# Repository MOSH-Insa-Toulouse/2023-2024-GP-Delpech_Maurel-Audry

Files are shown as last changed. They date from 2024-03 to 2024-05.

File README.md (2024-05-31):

# Projet-MOSH-INSA-Toulouse-2023-2024-Capteur-Graphite
## Implémentation d'un capteur de déformation/jauge de contrainte à base de graphite issu de crayons à papier HB à 2H.
Les jauges de contraintes sont des capteurs résistifs permettant de quantifier la déformation appliquée sur une structure. Ces capteurs sont souvent utilisés dans l'industrie car ils sont peu coûteux et facile à mettre en place. (Pencil Drawn Strain Gauges and Chemiresistors on Paper Cheng-Wei Lin, Zhibo Zhao, Jaemyung Kim & Jiaxing Huang Department of Materials Science and Engineering, Northwestern University 2220 Campus Drive, Evanston, IL, 60208, USA).
La mesure de résistance de ce type de crayon nécessite une amplification nous avons donc créé un Shield Arduino pour le traitement du signal et son affichage.

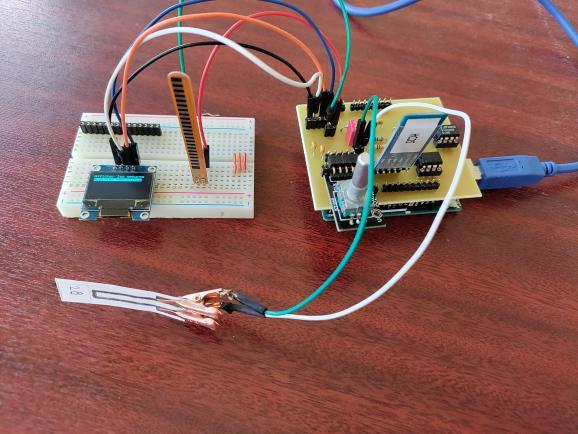
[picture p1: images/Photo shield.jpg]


## Livrables
- Un shield arduino permettant le conditionnement des mesures du capteur graphite, leur traitement et leur affichage.
- Une code arduino permettant le choix du gain de l'amplificateur, la communication en bleutooth via un module HC 05 et l'affichage des mesure sur un écran OLED.
- Une datasheet du capteur de contrainte low-tech

## Hardware utilisé
- 1 carte Arduino Uno
- 1 Module Bluetooth HC-05
- 1 Encodeur rotatoire
- 1 Écran OLED01
- 1 Flex sensor
- 1 Potentiomètre digital MCP-41050
- 1 AOP LTC1050

# Simulation du circuit amplificateur sur LTspice
Un circuit de transimpédance est utilisé pour elever le faible signal du capteur (100nA) à un signal lisible pour le microcontroleur de l'Arduino.

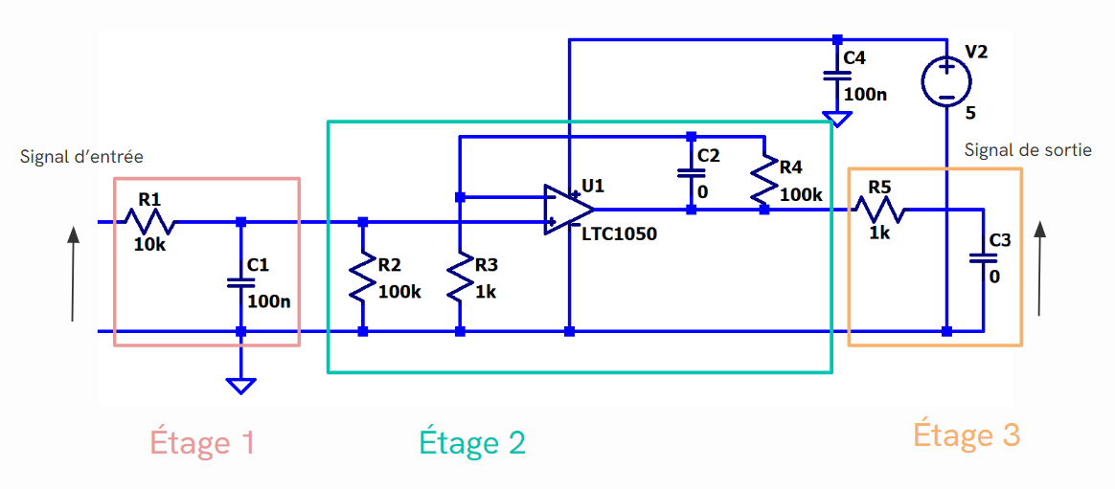
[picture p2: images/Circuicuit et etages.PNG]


Différents étages de filtres passes-bas permettent de couper les hautes fréquences et le 50 Hz et ainsi diminuer le bruit sur la mesure.
  - Fréquence de coupure de l'étage 1 : 16 Hz
  - Fréquence de coupure de l'étage 2 : 1.6 Hz
  - Fréquence de coupure de l'étage 3 : 1.6 kHz

La simulation permet de verifier qu'à 50 Hz le signal est atténué de -40 dB, le bruit du secteur seras alors grandement diminié et ne perturberas pas la mesure. 

# Design du PCB sur KiCAD et fabrication du shield

Le PCB inclu l'amplificateur de transimpédance et différents modules permettant l'affichage ou le traitment des données. En partant d’un template d’une carte Arduino Uno, il a fallu :
  - Reproduire la schématique du circuit transimpédance et créer de nouveaux symboles pour les modules spécifiques à notre projet.
  - Concevoir les empreintes réelles de ces modules en prenant en compte leurs caractéristiques physiques (nombres de pins, distance entre les pins, géométrie des empreintes…)
  - Effectuer le routage du circuit à partir du chevelu
  - Poser le plan de masse pour référencer les pistes au GND

## Schema et empreintes des modules

Module Bluetooth HC 05 : ce module permet la communication des données vers une application androide. L'implemantation d'un échange entre une application et le microcontrolleur permet le stockage de donnée que l'arduino ne permettrais pas. Il permet aussi d'avoir une vue d'ensemble sur les mesures que le petit écran ne permttrais pas.

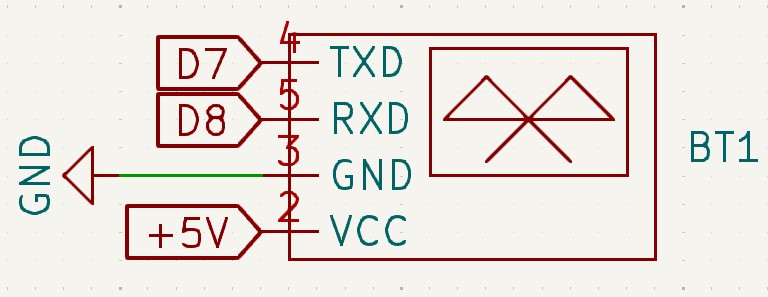
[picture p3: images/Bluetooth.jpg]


L'écran OLED : permet l'affichage des mesures et la selection du gain de l'amplificateur.

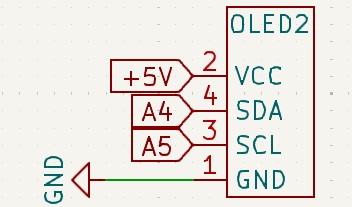
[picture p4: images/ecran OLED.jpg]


L'encodeur rotatoire : permet la navigation dans les menus. Le debouncing de l'encodeur a été réalisé en ajoutant des capacités sur les pins.

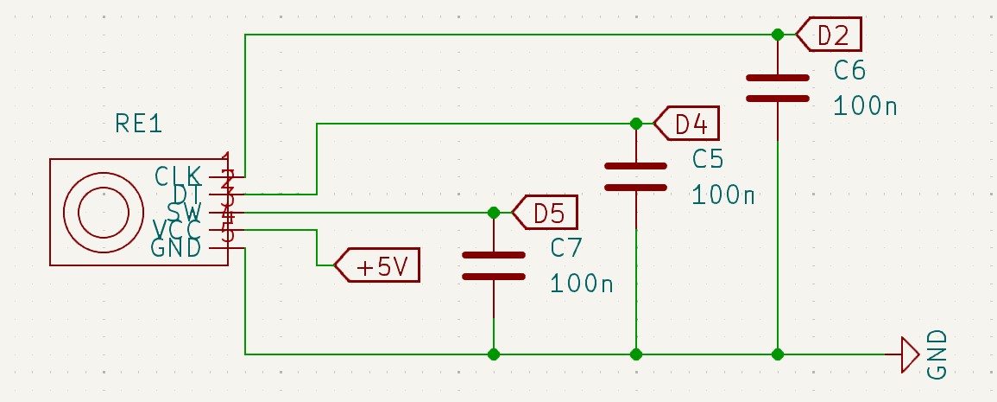
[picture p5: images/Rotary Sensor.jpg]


L'amplificateur de transimpédance avec le capteur graphite.

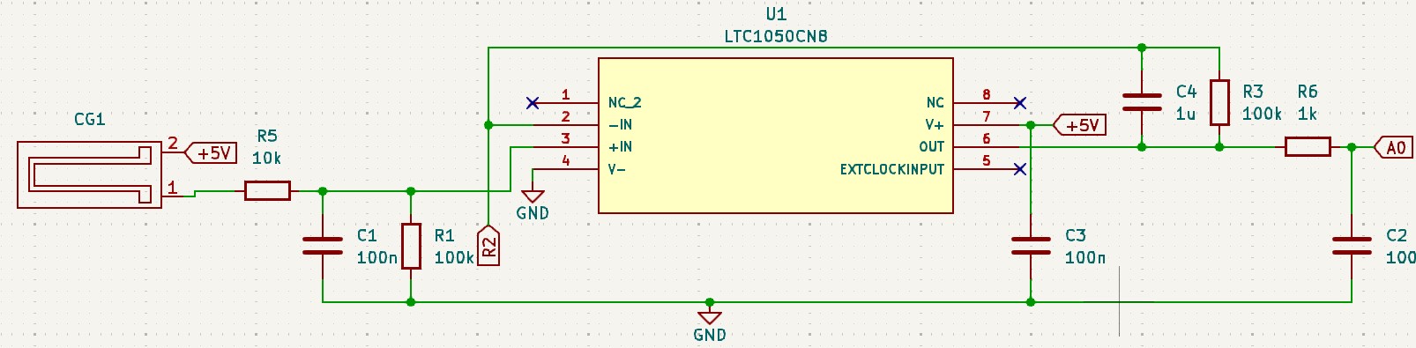
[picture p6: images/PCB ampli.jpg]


La résistance variable digitale MCP41050 : elle permet de changer la résistance R2 de l'amplificateur pour changer le gain.

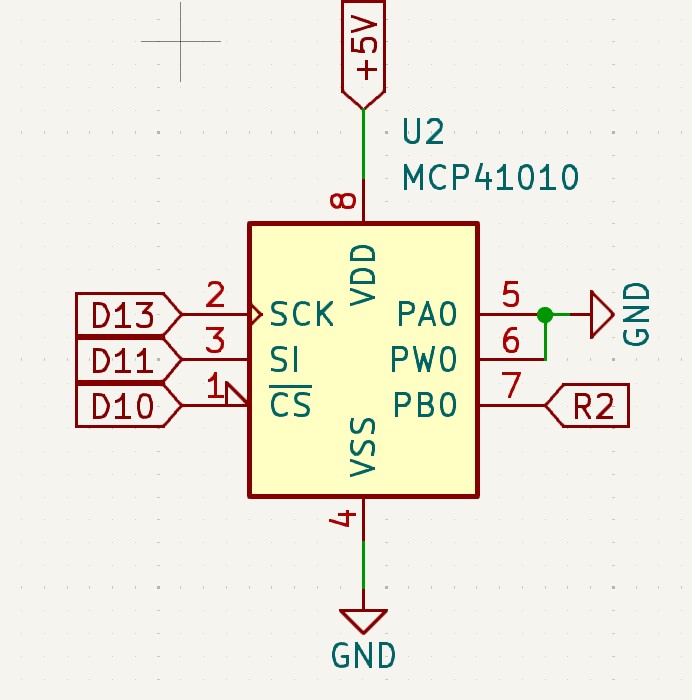
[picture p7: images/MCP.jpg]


## Schema du PCB complet

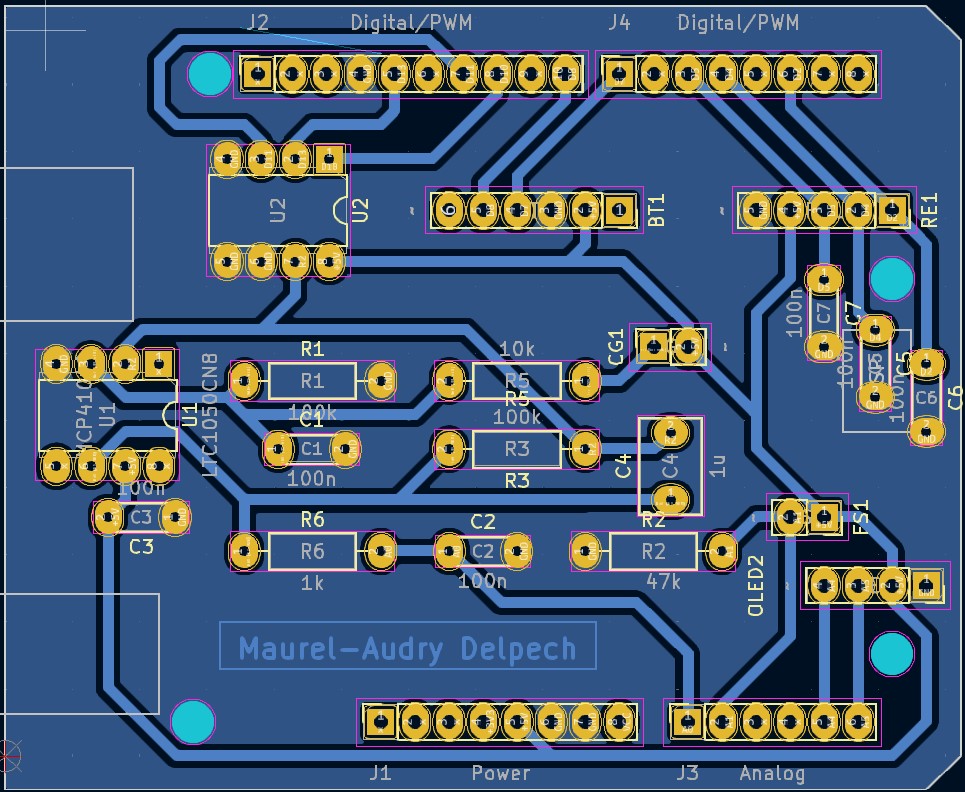
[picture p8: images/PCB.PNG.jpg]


## Fabrication du shield

Le shield est réalisé sur des plaques d'époxy recouvertes d'une couche de cuivre. Une résine photosensible est appliquée sur la plaque avec par dessus, le calque du circuit. Le tout est ensuit placé sous lumière UV pour faire polymeriser la résine au endroits non protégé par le calque. La plque d'époxy est ensuite plongé dans du perchlorure de fer pour retirer la couche de cuivre qui n'est pas protégé par la résine, faisant ainsi apparaître les circuits.

L'étape suivante est de percer les trous pour faire passer les pins de la carte et les composants. Une fois les trous percés, on soude les composants et les headers à la plaque.

# Code Arduino
Le code a été réalisé sous Arduino IDE 2.3.2 et il est consultable 
[ici](https://github.com/MOSH-Insa-Toulouse/2023-2024-GP-Delpech_Maurel-Audry/tree/main/Master_code_projet_capteur).

On utilise la bibliothèque Adafruit_SSD1306 pour gérer l'écran OLED sur lequel on affiche deux sous-menus.
Le premier permet d'afficher la tension après amplification du capteur graphite, la conversion de cette tension en une valeur de résistance et enfin la résistance du capteur de flexion. Le second permet de moduler la résistance du MCP_41050.
Pour naviguer entre les menus et moduler cette résistance, on utilise l'encodeur rotatoire et on clique sur le bouton pour valider ou revenir au menu précédent. 
Les mesures sont ensuite transférées à l'application Android via le module bluetooth. 

# Application android

Le petit écran OLED ne permet pas d'afficher un graph et la petite mémoire de l'arduino ne permet pas de conserver les mesures. Le rôle de l'application android est de pouvoir faciliter l'affichage et le stockage des valeures de déformation.
Pour utiliser l'appliication il faut, dans un premier temps, appairer le telephone au module Bleutooth grâce au menu déroulant de l'app (ne pas oublier d'autoriser l'application à utiliser le bluetooth).
Si le télephone est connecté, l'application recevras les données en continu et les reporteras sur le graphique déroulant. En parrallèle, l'application envoi aussi toutes les mesures sur une page google sheets pour le stockage.

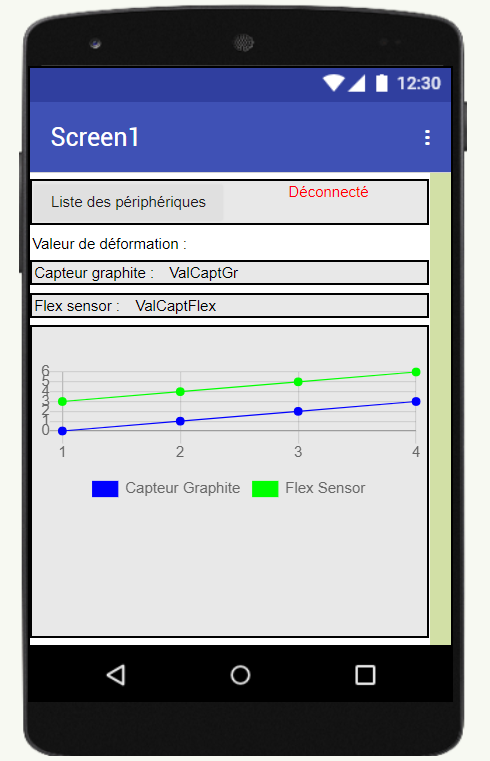
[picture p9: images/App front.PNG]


# Banc de test

Comme banc de test, nous avons utilisé 7 demi cylindres de différents diamètres allant de 2 à 5 cm avec un pas de 0,5 cm. La géométrie des cylindres est connue, il est possbile de remonter à la défromation avec la formule suivante :

$$\epsilon = \frac{e}{2r}$$ 
 
avec e l’épaisseur du capteur et r le rayon de courbure. Les mesures sont réalisées en tension.

2 des différents capteurs utilisés :

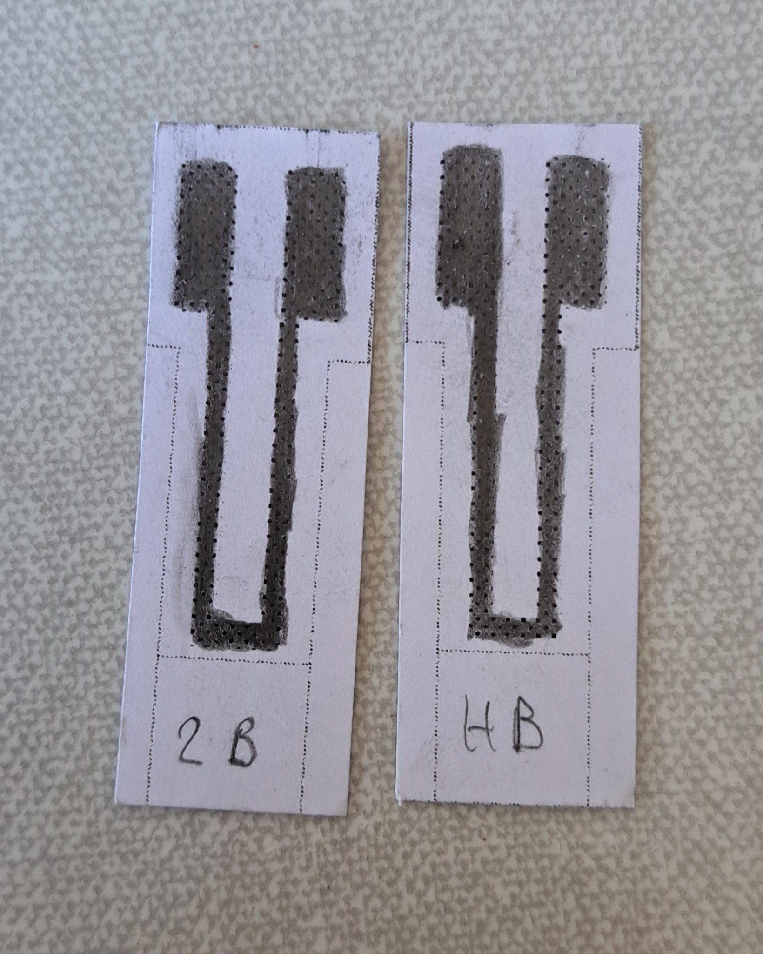
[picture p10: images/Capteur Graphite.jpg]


Suite aux mesures de résistance nous obtenons les courbes suivantes.
Pour l'extension :

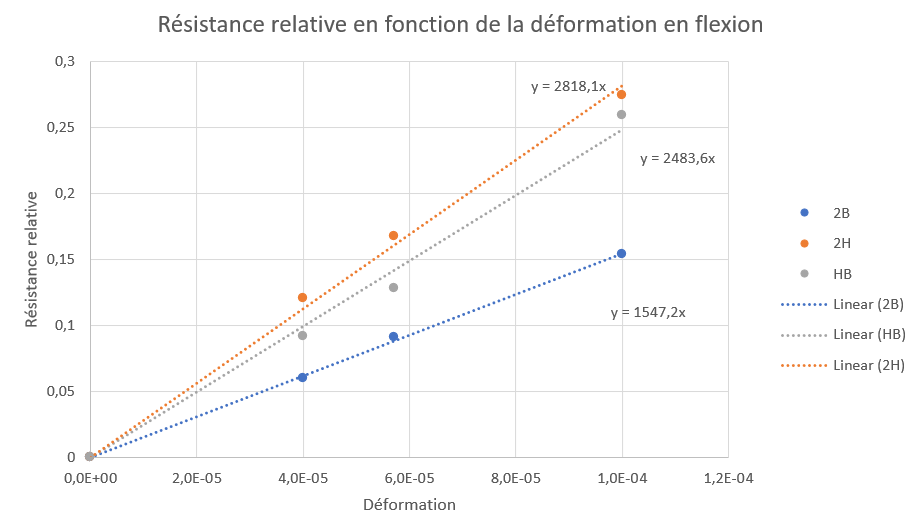
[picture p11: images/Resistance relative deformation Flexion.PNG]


Pour la compression :

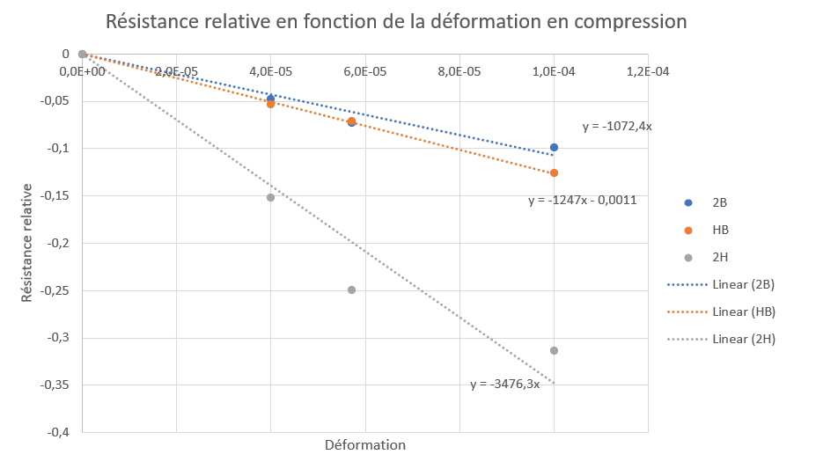
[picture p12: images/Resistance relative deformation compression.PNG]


# Datasheet
La fiche technique est consultable [ici](datasheet.pdf).

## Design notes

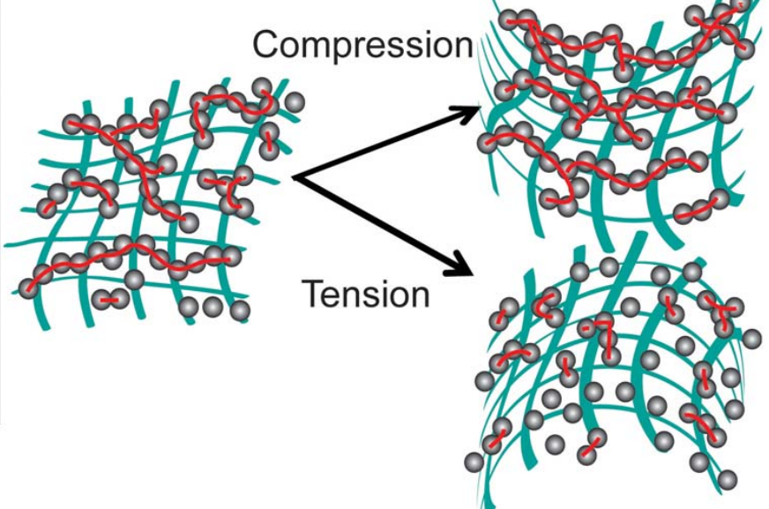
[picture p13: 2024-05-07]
images/Flexion compression.PNG

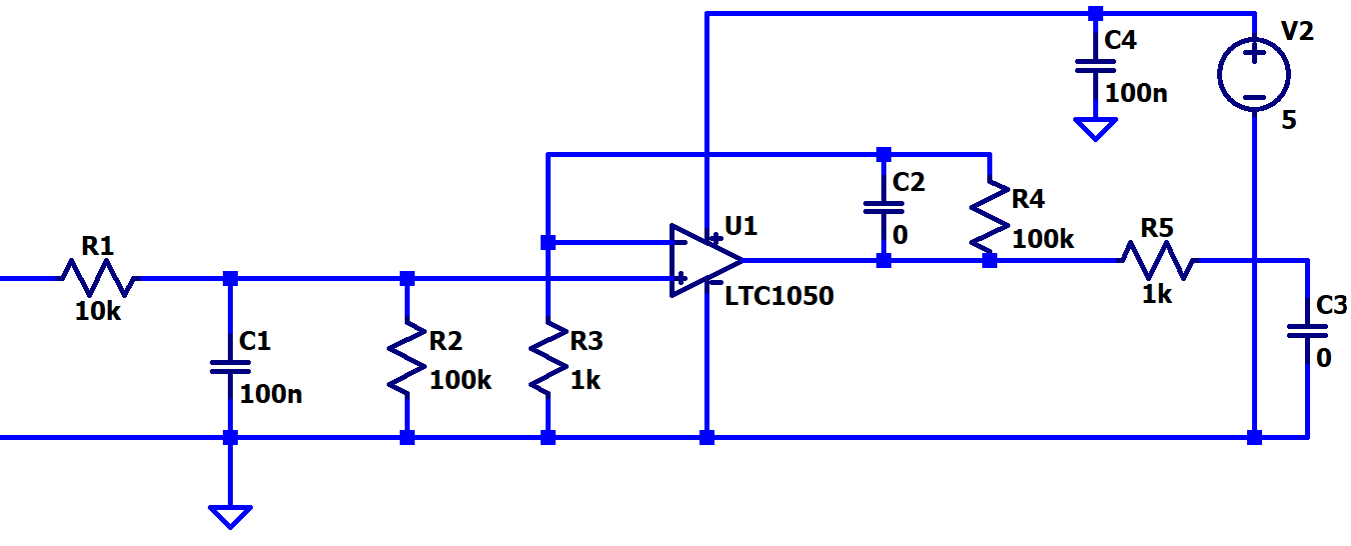
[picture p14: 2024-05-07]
images/circuitcuit.PNG

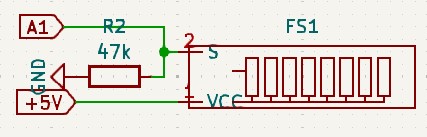
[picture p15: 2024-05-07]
images/Flex sensor.jpg

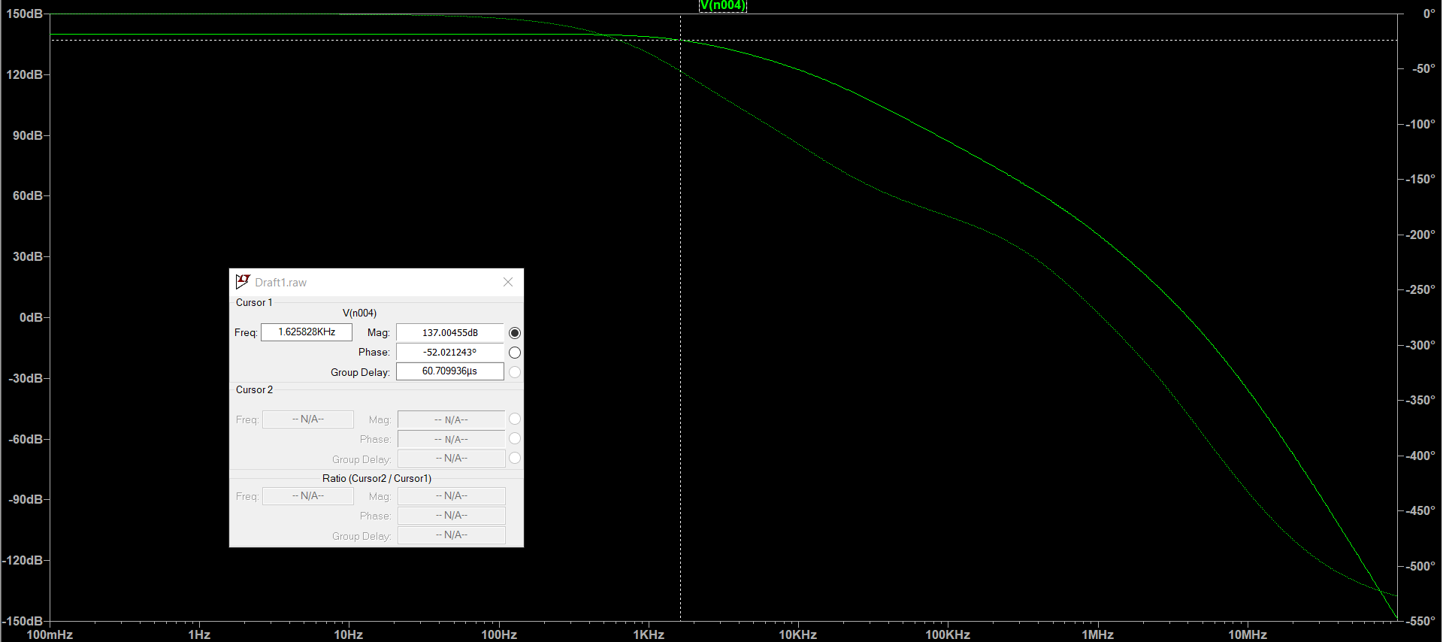
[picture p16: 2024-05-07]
images/Freq coupure 3eme etage.PNG

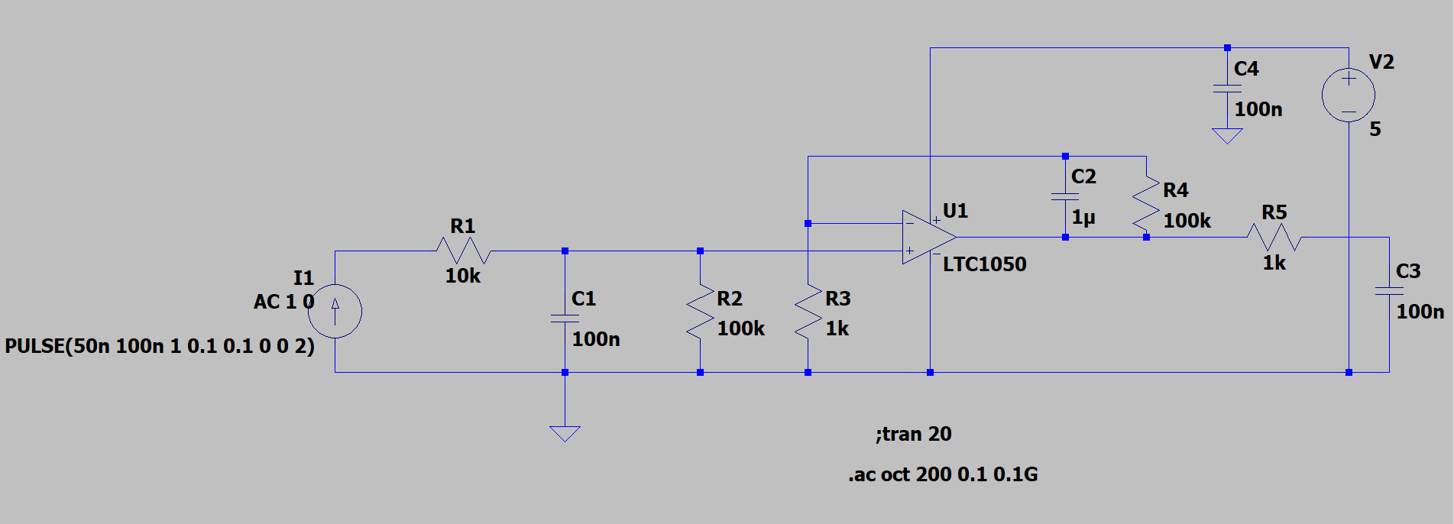
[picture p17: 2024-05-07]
images/Ciruitcuit.PNG

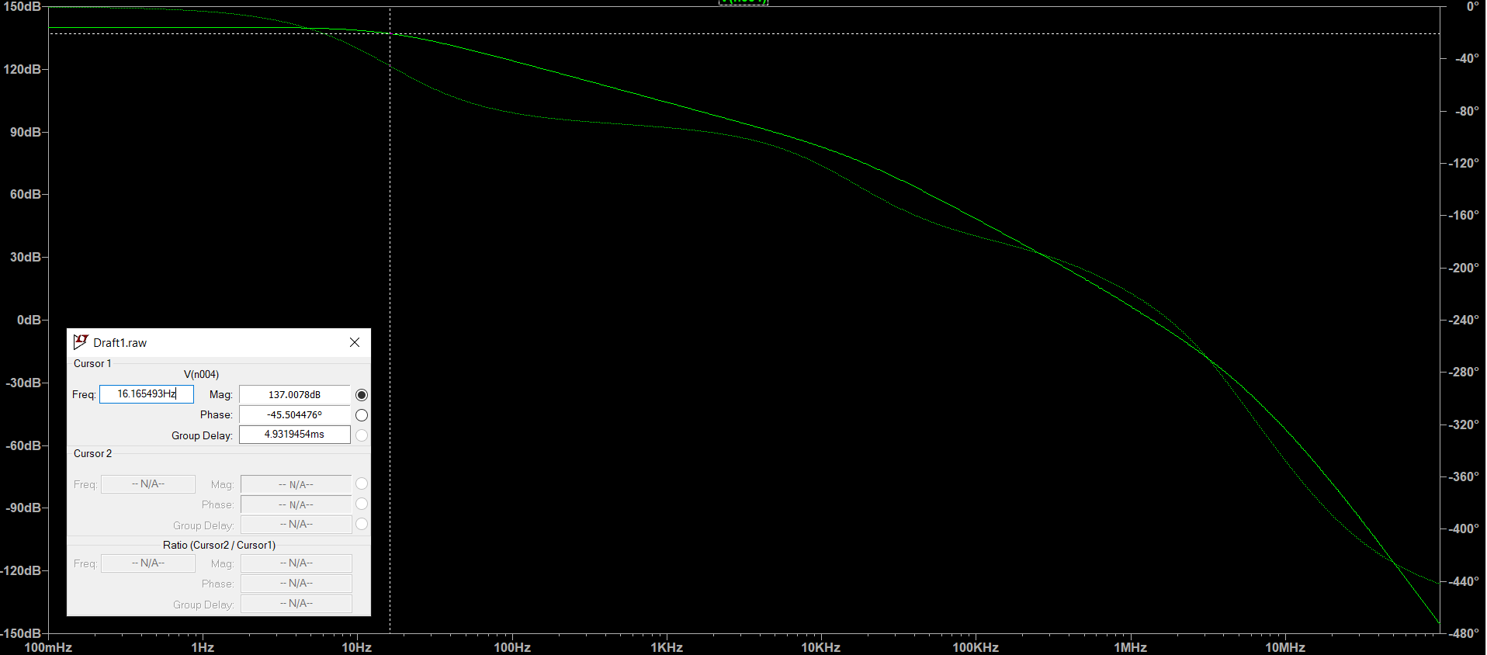
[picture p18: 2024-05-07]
images/freq coupure 1er etage.PNG

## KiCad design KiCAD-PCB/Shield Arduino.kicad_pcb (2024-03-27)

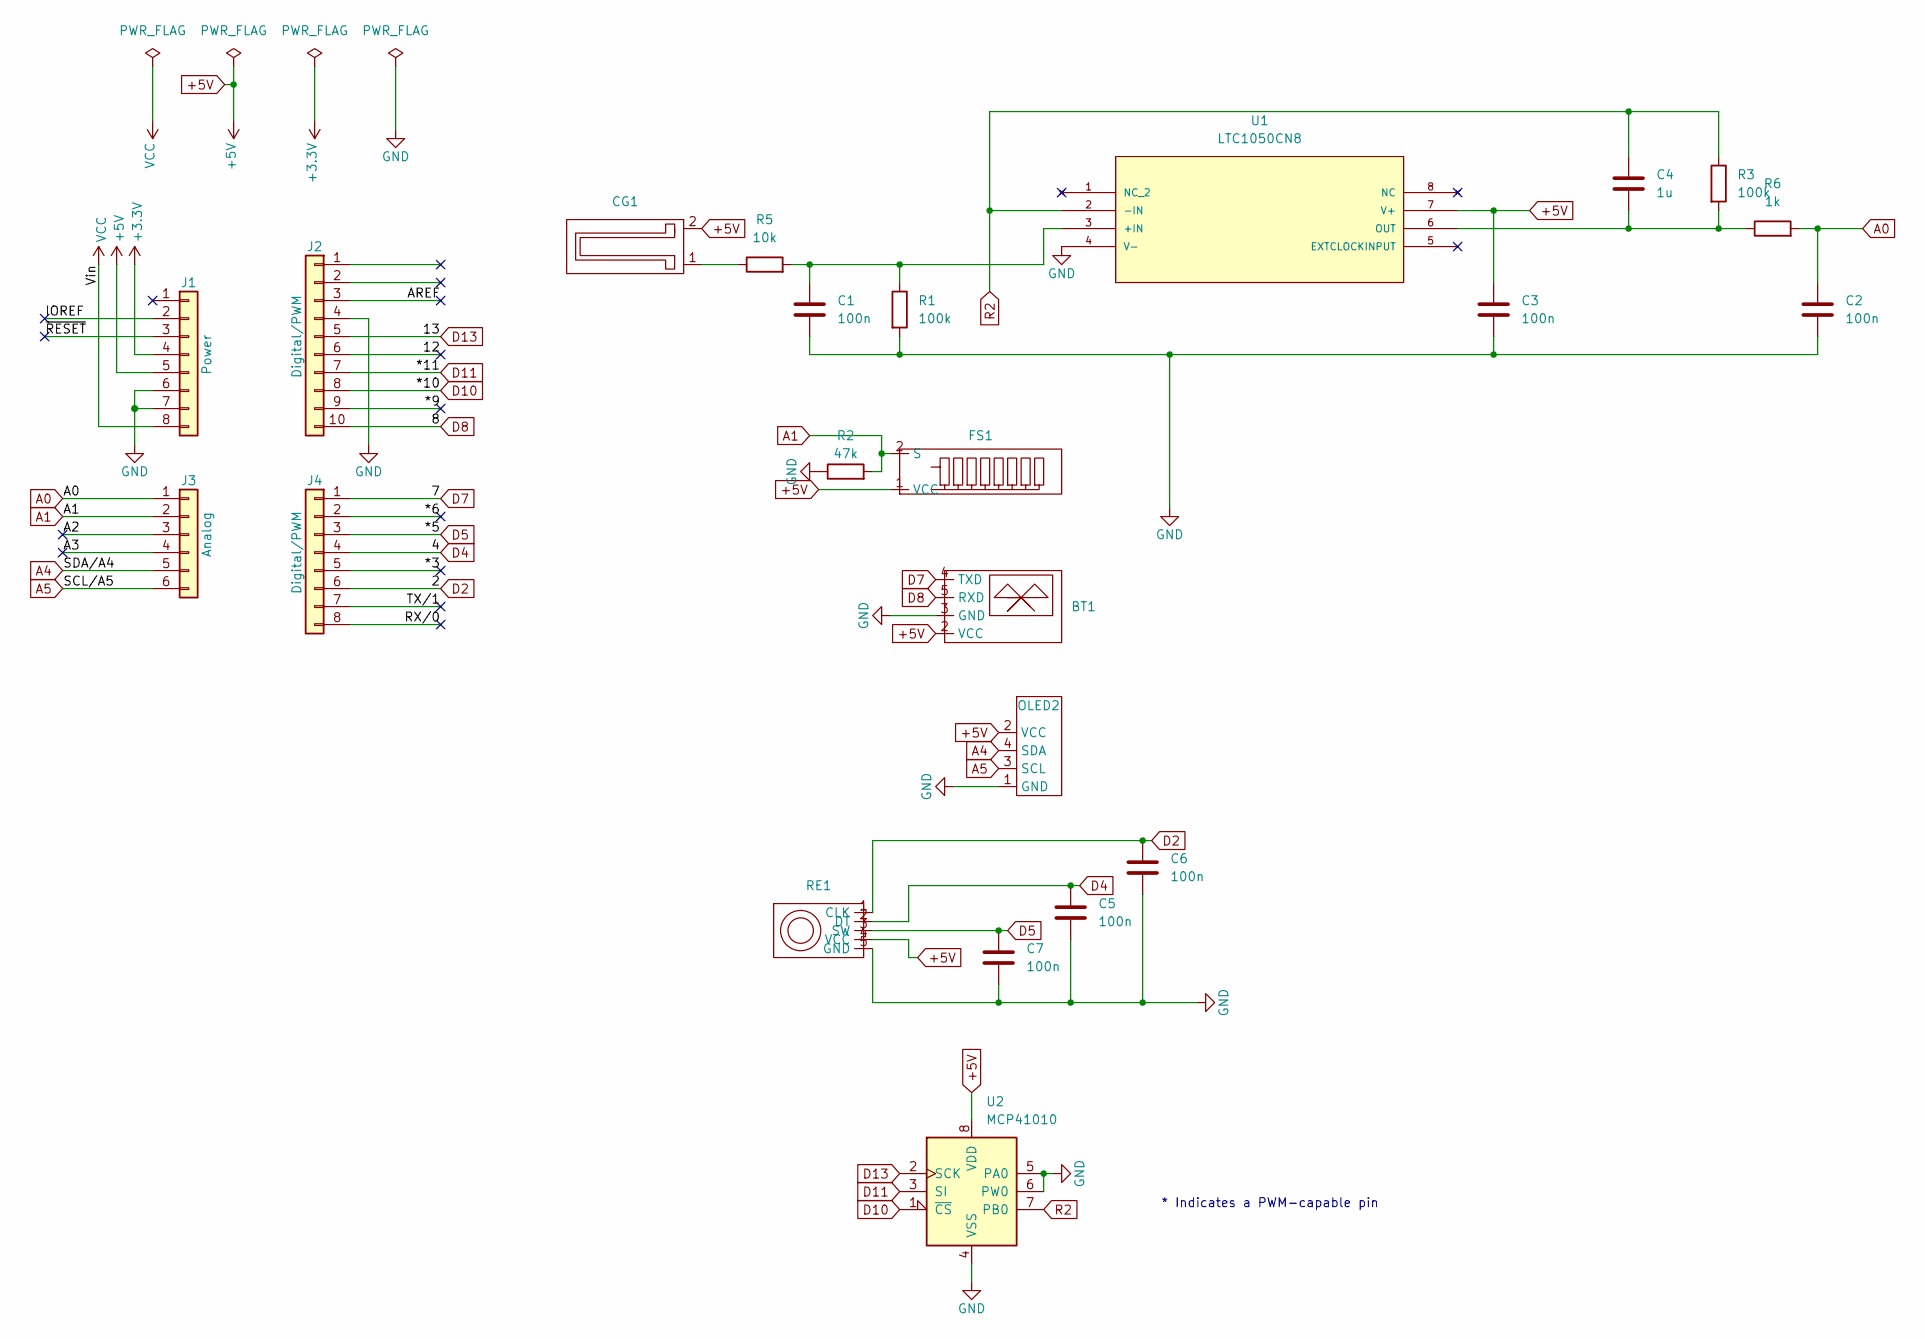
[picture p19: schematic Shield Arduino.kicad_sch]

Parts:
BT1: PinSocket_1x06_P2.54mm_Vertical
C1, C2, C3, C5, C6, C7: 100n; C_Disc_D4.3mm_W1.9mm_P5.00mm
C4: 1u; C_Rect_L7.0mm_W4.5mm_P5.00mm
CG1: PinSocket_1x02_P2.54mm_Vertical
FS1: PinSocket_1x02_P2.54mm_Vertical
J1: Power; PinSocket_1x08_P2.54mm_Vertical
J2: Digital/PWM; PinSocket_1x10_P2.54mm_Vertical
J3: Analog; PinSocket_1x06_P2.54mm_Vertical
J4: Digital/PWM; PinSocket_1x08_P2.54mm_Vertical
OLED2: PinSocket_1x04_P2.54mm_Vertical
R1, R3: 100k; R_Axial_DIN0207_L6.3mm_D2.5mm_P10.16mm_Horizontal
R2: 47k; R_Axial_DIN0207_L6.3mm_D2.5mm_P10.16mm_Horizontal
R5: 10k; R_Axial_DIN0207_L6.3mm_D2.5mm_P10.16mm_Horizontal
R6: 1k; R_Axial_DIN0207_L6.3mm_D2.5mm_P10.16mm_Horizontal
RE1: PinSocket_1x05_P2.54mm_Vertical
U1: LTC1050CN8; DIP-8_W7.62mm
U2: MCP41010; DIP-8_W7.62mm

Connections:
+3V3: J1.4
+5V: BT1.2 (VCC), C3.2, CG1.2, FS1.1 (VCC), J1.5, OLED2.2 (VCC), RE1.4 (VCC), U1.7 (V+), U2.8 (VDD)
/12: J2.6
/*3: J4.5
/*6: J4.2
/*9: J2.9
/A2: J3.3
/A3: J3.4
/AREF: J2.3
/IOREF: J1.2
/RX/0: J4.8
/TX/1: J4.7
/~RESET: J1.3
A0: C2.1, J3.1, R6.2
A1: FS1.2 (S), J3.2, R2.2
A4: J3.5, OLED2.4 (SDA)
A5: J3.6, OLED2.3 (SCL)
D2: C6.1, J4.6, RE1.1 (CLK)
D4: C5.1, J4.4, RE1.2 (DT)
D5: C7.1, J4.3, RE1.3 (SW)
D7: BT1.4 (TXD), J4.1
D8: BT1.5 (RXD), J2.10
D10: J2.8, U2.1 (~CS)
D11: J2.7, U2.3 (SI)
D13: J2.5, U2.2 (SCK)
GND: BT1.3 (GND), C1.2, C2.2, C3.1, C5.2, C6.2, C7.2, J1.6, J1.7, J2.4, OLED2.1 (GND), R1.2, R2.1, RE1.5 (GND), U1.4 (V-), U2.4 (VSS), U2.5 (PA0), U2.6 (PW0)
unnamed: CG1.1, R5.1
unnamed: C1.1, R1.1, R5.2, U1.3 (+IN)
unnamed: C4.1, R3.2, R6.1, U1.6 (OUT)
R2: C4.2, R3.1, U1.2 (-IN), U2.7 (PB0)
VCC: J1.8

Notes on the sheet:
* Indicates a PWM-capable pin

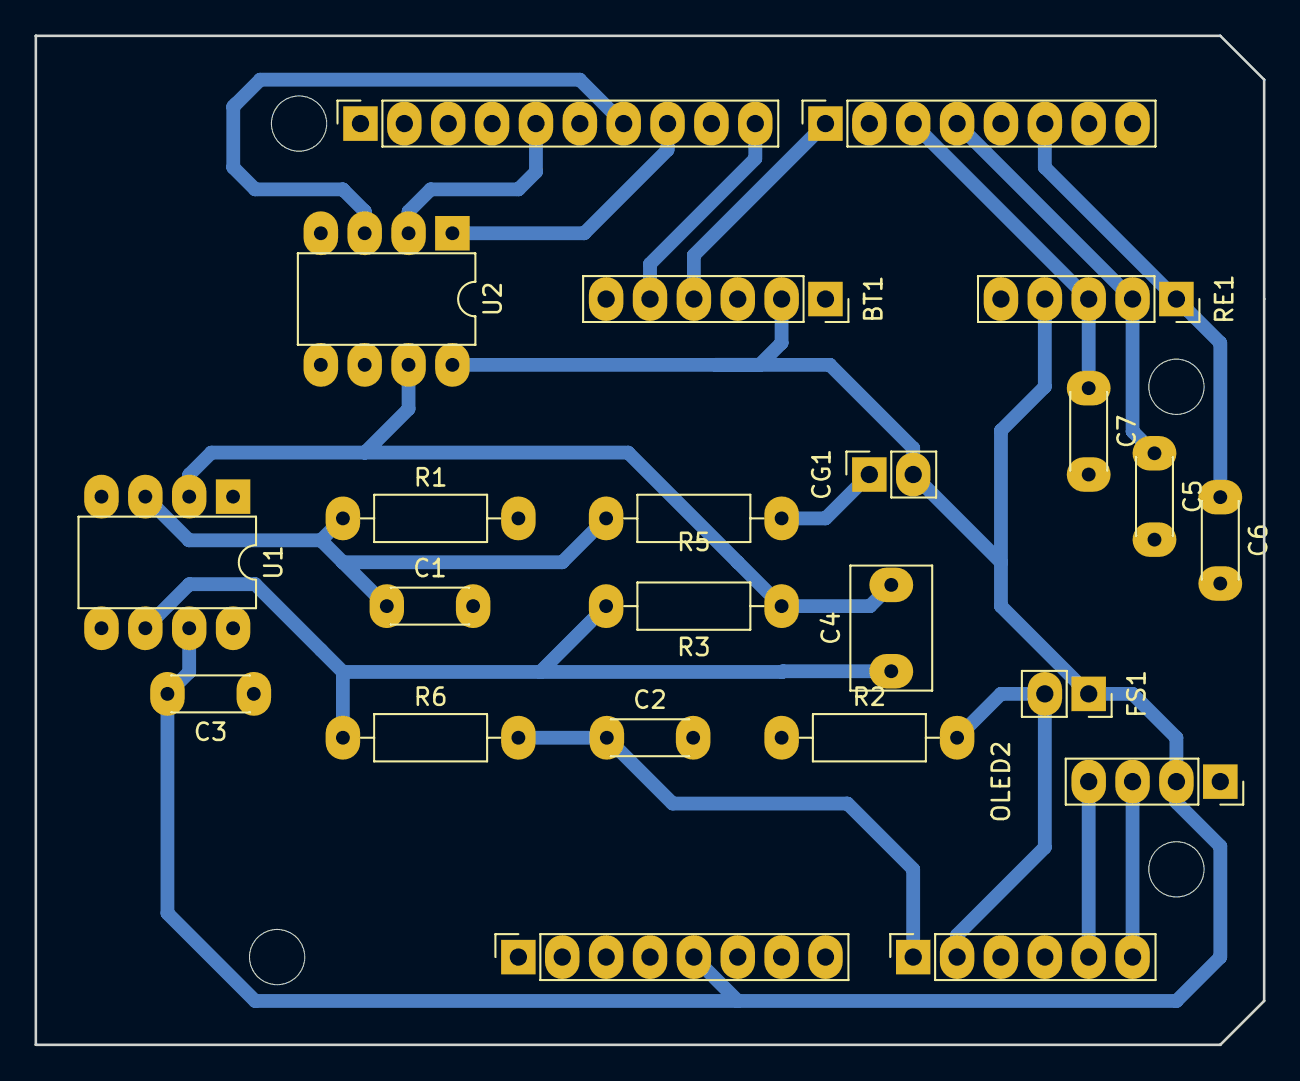
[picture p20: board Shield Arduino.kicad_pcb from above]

Board: 2 copper layers, 71.1 x 58.4 mm, 27 parts (0 on the bottom side), 18 nets.

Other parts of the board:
MH1, MH2, MH3, MH4: MountingHole_3.2mm

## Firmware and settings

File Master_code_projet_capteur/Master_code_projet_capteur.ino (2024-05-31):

#include <Wire.h>
#include <Adafruit_GFX.h>
#include <Adafruit_SSD1306.h>
#include <SPI.h>
#include <SoftwareSerial.h>


//Définition des pins analogiques pour les capteurs

#define PIN_GRAPH_SENSOR A0 // Capteur graphite sur l'entrée analogique A0
#define PIN_FLEX_SENSOR A1 // Capteur de flexion sur l'entrée A1

// Définition des pins numériques pour l'encodeur rotatoire
#define CLK  2  
#define DT  4  
#define Switch 5 

//Définition des broches RXD et TXD du module Bluetooth HC-05
#define bluetoothTx 7 // Broche TXD du module Bluetooth connectée à la broche 7 d'Arduino
#define bluetoothRx 8 // Broche RXD du module Bluetooth connectée à la broche 8 d'Arduino

// Déclaration d'un objet de type SoftwareSerial pour la communication avec le module Bluetooth
SoftwareSerial bluetooth(bluetoothTx, bluetoothRx);

// Déclaration de l'écran OLED avec la bibliothèque AdaFruit

#define SCREEN_WIDTH 128    // Taille horizontale de l'écran OLED  
#define SCREEN_HEIGHT 64    // Taille verticale 
#define OLED_RESET    -1    // Reset de l'écran est le même que celui de l'Arduino Uno
#define SCREEN_ADDRESS 0x3C // Adresse I2C de l'écran

Adafruit_SSD1306 oled(SCREEN_WIDTH, SCREEN_HEIGHT, &Wire, OLED_RESET);

// Déclaration pour les menus de l'écran
int selectedItem = 0;
bool inSubMenu = false;
const int numItems = 2;
const char *menuItems[] = {"Afficher les mesures", "Modifier resistance"};

// Déclaration pour le potentiomètre digital
const byte csPin           = 10;      
const int  maxPositions    = 256;     
const long rAB             = 50000.0;    
const byte rWiper          = 125;     
const byte pot0            = 0x11;    // pot0 addr // B 0001 0001
const byte pot0Shutdown    = 0x21;    // pot0 shutdown // B 0010 0001
int pos_res_variable = 5; // Fixe la résistance initiale du potentiomètre digital

// Déclaration pour le capteur de flexion et le capteur graphite
const float VCC = 5;
const float flexR_DIV = 39000.0;
const float flexflatResistance = 25000.0;
const float flexbendResistance = 100000.0;
float tension_graphite = 0;
float tension_flex = 0;
long resistance_variable = 0;
float resistance_graphite = 0;
long resistance_flex = 0;
char resultGraphite[15];
char buffer[15];
char resultFlex[15];
char buffer_flex[15];

// Déclaration pour l'encodeur rotatoire
volatile unsigned int lastStateSW; // variable qui enregistre l'état du bouton à la boucle précédente

/* ~~~~ Initialisation du programme ~~~~~ */

void setup() {
  Serial.begin(9600);
  bluetooth.begin(9600);
  
 // Initialisation des pins 
  pinMode(CLK, INPUT_PULLUP);
  pinMode(DT, INPUT_PULLUP);
  pinMode(Switch, INPUT_PULLUP);
  pinMode(PIN_GRAPH_SENSOR, INPUT);
  pinMode(PIN_FLEX_SENSOR, INPUT);
    
  lastStateSW = digitalRead(Switch); // Vérifie l'état du bouton au lancement du programme

  attachInterrupt(0, doEncoder, RISING); //Définit l'interruption lorsque l'encodeur rotatoire tourne
 
 // Initialisation de l'écran
 if(!oled.begin(SSD1306_SWITCHCAPVCC, SCREEN_ADDRESS)) {
    Serial.println(F("SSD1306 allocation failed"));
    for(;;);
  }
  oled.setTextSize(1);
  oled.display();
  delay(2000);
  oled.clearDisplay();

 // Initialisation de la communication avec le potentiomètre digital
  digitalWrite(csPin, HIGH);        
  pinMode(csPin, OUTPUT);           
  SPI.begin();

}

/* ~~~~ Programme principal ~~~~~ */

void loop() {

  // Lecture de l'état du bouton pour passer du menu et aux sous-menus
  int stateSW = digitalRead(Switch);
  if (stateSW != lastStateSW && stateSW == LOW) {
    Serial.println(F("Clic!"));
    inSubMenu = !inSubMenu;
  }
  lastStateSW = stateSW;

  setPotWiper(pot0,pos_res_variable); // Modifie la résistance du potentiomètre

 // Mesures des capteurs et résistance variable
 tension_graphite = analogRead(PIN_GRAPH_SENSOR)*VCC/1023.0 ;
 resistance_variable = ((rAB * pos_res_variable) / maxPositions ) + rWiper;
 resistance_graphite = ((1+ (100000/resistance_variable))*100000*(VCC/tension_graphite)-110000)/1000000;
  
 tension_flex = analogRead(PIN_FLEX_SENSOR) *VCC/1023;

 resistance_flex = flexR_DIV * (VCC / tension_flex - 1);
 

 // Gestion de l'affichage sur l'écran
  oled.clearDisplay();

 if (!inSubMenu) {
    for (int i = 0; i < numItems; ++i) {
      if (i == selectedItem) {
        oled.setTextColor(SSD1306_BLACK, SSD1306_WHITE);
      } else {
        oled.setTextColor(SSD1306_WHITE);
      }
      oled.setCursor(0, i * 10);
      oled.println(menuItems[i]);
    }
  } 
  else {
    oled.setTextColor(SSD1306_WHITE);
    oled.setCursor(0,0);

    switch(selectedItem){ 

      case(0):
        oled.println(F("Tension graphite :  "));
        oled.print(tension_graphite);
        oled.println(F(" V"));
        oled.println();
        oled.println (F("Resistance graphite :"));
        oled.print(resistance_graphite);
        oled.println(F(" MOhms"));
        oled.println();
        oled.println(F("Resistance flex : "));
        oled.print(resistance_flex);
        oled.println(F(" Ohms"));
        break;

      case(1):             
        
        oled.println(F("Resistance variable :"));
        oled.print(resistance_variable);
        oled.println(F(" Ohms"));
        oled.println();
        oled.println(F("Tension graphite :  "));
        oled.print(tension_graphite);
        oled.println(F(" V"));
                        
        break;

      default:
        oled.println(F("la reponse D"));
        break;

    }
    
  }
  
  oled.display();
  

  // Bluetooth
  dtostrf(tension_graphite, 4, 2, buffer); // Transforme la mesure float en une chaîne de caractères    
    
  sprintf(resultGraphite,"g%s\n", buffer); //remplit le tableau resultGraphite de la mesure au format g"mesure"\n pour que l'appli puisse la lire
  bluetooth.write(resultGraphite); // envoie le contenu du tableau vers le module bluetooth
  delay(100);    
  
  dtostrf(tension_flex, 4, 2, buffer_flex);
  sprintf(resultFlex,"f%s\n",buffer_flex);
  bluetooth.write(resultFlex);
    
  if (bluetooth.available()) {
    // Lit les données reçues depuis le module Bluetooth
    char receivedChar = bluetooth.read();
    
    // Affiche les données reçues sur le moniteur série
    Serial.print(receivedChar);
  }

  delay(100);
}

/* ~~~~ Fonctions supplémentaires ~~~~ */


// Fonction lors de l'interrupt de l'encodeur rotatoire
void doEncoder() {
  // Cas du menu principal
  if(!inSubMenu){ 
    if (digitalRead(DT)==HIGH) {
        selectedItem = (selectedItem == 0) ? numItems - 1 : selectedItem - 1;    // Dans le sens horaire fait défiler vers le bas puis boucle vers le premier item de la liste
    }
    else {
          selectedItem = (selectedItem == numItems - 1) ? 0 : selectedItem + 1; // L'inverse pour le sens trigonomètrique
    }
  }
  /* Cas du sous-menu de choix du gain

  La rotation permet, par incrément de 1, de changer une position entre 0 et 255 correspondant
  aux différentes valeurs de résistances possibles du potentiomètre digital.

  */
  else {
    if (selectedItem == 1) {
      if (digitalRead(DT)==HIGH) {      
        pos_res_variable++;
        if (pos_res_variable >= 255) {
          pos_res_variable= 255;
        }
      }
      else {
      
      pos_res_variable--;
      if (pos_res_variable <= 0) {
       pos_res_variable= 0;
      }
      }
    }
      
  }  
}

// Fonction de modulation de la résistance du potentiomètre digital
void setPotWiper(int addr, int pos) {
  pos = constrain(pos, 0, 255);            
  digitalWrite(csPin, LOW);                
  SPI.transfer(addr);                      
  SPI.transfer(pos);
  digitalWrite(csPin, HIGH);               
}
